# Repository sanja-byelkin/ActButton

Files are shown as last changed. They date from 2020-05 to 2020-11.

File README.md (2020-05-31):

# ActButton

It is a software for MQTT button.
On pressing button it:
* switches its power on
* connects to a Wifi
* connects to a MQTT server
* sends a message to a topic you setup (voltage * 1000)
* switches itself off

(above takes several seconds)

# Setup

If the button was not setup or can not connect to wifi or you continue to
press button for long time (about 12 sec) it will create Wifi network for
setup (then you can release button).

Default wifi for setup is "ActButton" and password is "ab1234567890ab" (it
can (and shoud!) be changed in setup). When you connect to the setup Wifi all web
connections will redirected to the button setup web page.
On the setup page there is http buttons:
* OK - save parameters and shutdown
* CANCEL - shutdown
* RESET - remove setup (format data partition of the esp8266 flash) and shutdown
* UPDATE - update software with given file and restart

# Hardware

* D1 Mini ESP8266 module
* LiFePo4 14500 (500mAh) battery
* ndp6020p MOSFET
* 1000 µF Electrolitic capasitor
* push button

# Circuit

Idea by Andreas Spiess ( https://www.youtube.com/channel/UCu7_D0o48KbfhpEohoP7YSQ )

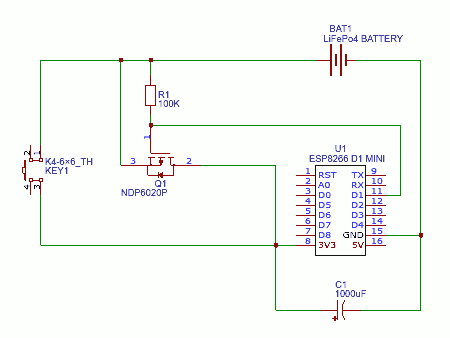
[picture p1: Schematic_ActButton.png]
ActButton Schematic


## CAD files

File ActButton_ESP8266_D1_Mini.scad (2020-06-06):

$fn=50;
WALL= 0.4*3;
S_WALL= 0.2;
TOLLERANCE= 0.03;

// no belt if 0
BELT_THICKNESS= 0.7;
BELT_W= 20;
BELT_ANGLE= 45;

VOLUME_2= "COMBO"; // "MIN", "MID", "MAX", "COMBO"


BATT_D= 14.5 + TOLLERANCE*2 + BELT_THICKNESS*2;
BATT_L= 50.5 + TOLLERANCE*2;
CAPACITOR_D= 14.5 + TOLLERANCE*2;
CAPACITOR_L= 22 + TOLLERANCE*2;
ESP_W= 26 + TOLLERANCE*2;
ESP_L= 35 + TOLLERANCE*2;
ESP_H= 10 + TOLLERANCE*2;
ESP_RH= 2;

CONT_D= 1.2;
CONT_M= 5 - CONT_D;
CONT_P= 3 - CONT_D;

BUTTON_PLATFORM= 10;
BUTTON_GAP= 4.2;
BUTTON_PRESS= 4;
BUTTON_OVERLAP= 0.4;
BUTTON_WALL_GAP=4;

LED_WINDOW= 12;



BOX_W= max(5*WALL + BATT_D + CAPACITOR_D,
           3*WALL + ESP_W);
BOX_L= max(4*WALL + BATT_L,
           2*WALL + CAPACITOR_L,
           2*WALL + ESP_L);
BOX_H= 4*WALL + max(BATT_D, CAPACITOR_D) + ESP_H;

BUTTON_WINDOW_L= (BUTTON_WALL_GAP*2 + BUTTON_PLATFORM -2*WALL);
BUTTON_WINDOW_W= BOX_W-6*WALL;

// cutting tool for cut_cube
module cuting_side(x,y,a)
{
    h= x*tan(a);
    rotate([90,0,0])
    linear_extrude(height=y, center=true)
    polygon(points = [[0,0],[x,0],[x,h]]);
}

// cube with well-printed "supports"
module cut_cube(dim, angle)
{
    down= max(dim[0], dim[1])/2*tan(angle);
    h= dim[2] + down;
    translate([0, 0 , +h/2 -(down + dim[2]/2)])
    difference()
    {
        cube([dim[0], dim[1], h], center=true);
        translate([0, 0 , -h/2])
        cuting_side(x= dim[0]/2, y= dim[1], a=angle);
        translate([0, 0 , -h/2])
        mirror([1,0,0])
        cuting_side(x= dim[0]/2, y= dim[1], a=angle);
        translate([0, 0 , -h/2])
        rotate([0,0,90])
        cuting_side(x= dim[1]/2, y= dim[0], a=angle);
        translate([0, 0 , -h/2])
        mirror([0,1,0])
        rotate([0,0,90])
        cuting_side(x= dim[1]/2, y= dim[0], a=angle);
    }
}

// long and overcomplicated way to make a barierr
module cubic_barrier(h,l,r,cut)
{
    hh= sqrt(h*h/2);
    difference()
    {
        translate([0,0,h/2])
        rotate([0,45,0])
        cube([hh,l,hh], center= true);
        if (cut)
        {
            translate([(r? -hh : 0),-(l+1)/2,-1])
            cube([hh,l+1,h+2]);
        }
    }
}

// something 1-like shaped
module limit_w_barrier(w,l,h1,h2,r)
{
    translate([-w/2,-l/2,0])
    cube([w,l,h1+h2]);
    translate([(r?w/2:-w/2),0,h1])
    cubic_barrier(h=h2,l=l,r=r, cut=false);
}

// Cage for 6x6mm button
module button_66cage(platform, gap)
{
    // 6x6mm button parameters
    BUTTON_SL= 3.5;
    BUTTON_S= 6;
    BUTTON_SH= 4;
    BUTTON_B= 0.5;
    translate([0, 0, gap/2])
    cut_cube([platform, BUTTON_SL, gap +0.01], angle=45);
    translate([0, 0, gap/2])
    cut_cube([BUTTON_SL, platform, gap +0.01], angle=45);
        
    // real botton cage
    barier= (platform-BUTTON_S)/2 - TOLLERANCE;
        
    translate([(platform/2 - barier/2), 0, gap - 0.01])
    limit_w_barrier(l= BUTTON_SL, w= barier, h1= BUTTON_SH + 0.01, h2=BUTTON_B,r=false);

    translate([-(platform/2 - barier/2), 0, gap - 0.01])
    limit_w_barrier(l= BUTTON_SL, w= barier, h1= BUTTON_SH + 0.01, h2= BUTTON_B, r= true);
        
    translate([0, (platform/2 - barier/2), gap - 0.01])
    rotate(90)
    limit_w_barrier(l= BUTTON_SL, w= barier,h1= BUTTON_SH + 0.01, h2= BUTTON_B, r= false);
        
    translate([0, -(platform/2 - barier/2), gap - 0.01])
    rotate(90)
    limit_w_barrier(l= BUTTON_SL, w= barier,h1= BUTTON_SH + 0.01, h2= BUTTON_B, r= true);
}

// D shaped cut to put cylinder in it
module cylinder_cut(d, l, h)
{
    cylinder(d=d, h=l, center= true);
    translate([0, -h/2, 0])
    cube([d, h, l], center= true);
}

// "swift-tail" :)
module s_tail(w1,w2,l,h)
{
    rotate([90,0,0])
    linear_extrude(height=l, center=true)
    polygon(points = [[-w1/2,-h/2],
                      [-w2/2,+h/2],
                      [+w2/2,+h/2],
                      [+w1/2,-h/2]]);
}

// slider-cover shape
module slider_cover(h, w, l, top)
{
    ww= w + 2*h;
    difference()
    {
        union()
        {
            translate([0, 0, h/2])
            if (top)
                s_tail(w1=w, w2=ww, l=l, h=h);
            else
                s_tail(w1=ww, w2=w, l=l, h=h);
            translate([0, +h - l/2, -h/2 +0.01])
            cube([ww, h*2, h], center=true);
            translate([0, -h + l/2, -h/2 +0.01])
            cube([ww, h*2, h], center=true);
            translate([0, 0, -h/2 +0.01])
            cube([w, l - h*4, h], center=true);
        }
        translate([-h/2 + ww/2, -h + l/2, 0])
        cube([h, h*2, 8*h], center=true);
        translate([+h/2 - ww/2, -h + l/2, 0])
        cube([h, h*2, 8*h], center=true);
    }
}

// Cut for battery contacts
module battery_cont(cd, centers_d, ch, cut)
{
    translate([+centers_d/2, 0, 0])
    cylinder(d= cd, h= ch, center=true);
    translate([-centers_d/2, 0, 0])
    cylinder(d= cd, h= ch, center=true);
    translate([0, 0, +cut/2 - ch/2])
    cube([centers_d, cd, cut], center=true);
}

// The box without cuts for its battery compartment
module button_top_cut_box()
{
    battery_comp= 3*WALL + BATT_D;
    difference()
    {
        // box
        cube([BOX_W, BOX_L, BOX_H], center= true);

        // Cut for electronics
        translate([0, 0, -(BOX_H - battery_comp)/2 + BOX_H/2 + 0.01])
        cube([BOX_W - 4*WALL, BOX_L - 2*WALL, BOX_H -  battery_comp], center= true);
        translate([+(CAPACITOR_D/2) - (BOX_W/2 - 2*WALL), 0, - (CAPACITOR_D/2 + BOX_H/2) + (VOLUME_2 == "MIN" ? (battery_comp + ESP_RH) : (CAPACITOR_D + WALL))])
        if (VOLUME_2 == "MIN" || VOLUME_2 == "MID")
        {
            rotate([-90, 0, 0])
            cylinder_cut(d= CAPACITOR_D, l= BOX_L - 2*WALL, h= BOX_H);
        }
        else
        {
            //if there is belt, lets mame its cut even
            cl= min(CAPACITOR_L, (BELT_THICKNESS > 0 ? (BOX_L - 2*WALL - BELT_W - 2*WALL)/2 : BOX_L));
            l= BOX_L - 2*WALL - (VOLUME_2 == "MAX" ? 0: cl);
            translate([ 0, (VOLUME_2 == "MAX" ? 0 : - -cl/2), BOX_H/2 - CAPACITOR_D/2])
            difference()
            {
                cube([CAPACITOR_D, l, BOX_H], center=true);
                translate([ CAPACITOR_D/4, 0, -BOX_H/2])
                rotate([90,0,0])
                linear_extrude(height= l, center=true)
                polygon(points = [[0,0],[CAPACITOR_D/4, 0],[CAPACITOR_D/4,CAPACITOR_D/4]]);
            }
            if (VOLUME_2 != "MAX")
            {
                translate([0, -l/2 +WALL/2, (battery_comp + ESP_RH)
                - (CAPACITOR_D + WALL)])
                rotate([-90, 0, 0])
                cylinder_cut(d= CAPACITOR_D, l= cl+ WALL, h= BOX_H);
            }
        }
        
    }
    translate([0, BOX_L/2- WALL - BUTTON_PLATFORM/2 -BUTTON_GAP, -BOX_H/2 + BATT_D + 3*WALL])
    button_66cage(platform= BUTTON_PLATFORM, gap=BUTTON_GAP);
}

// The box body
module button_box()
{
    difference()
    {
        button_top_cut_box();

        // Battery compartment
        translate([-(BATT_D/2) + (BOX_W/2 - 2*WALL), 0, (BATT_D/2) - (BOX_H/2 - 2*WALL)])
        rotate([90, 0, 0])
        cylinder_cut(d= BATT_D, l= BATT_L, h= BATT_D/2+ 2*WALL + 0.01);
        // Cut for battery cover
        translate([-(BATT_D + 2*WALL)/2 + BOX_W/2 - WALL, 0, +WALL - BOX_H/2])
        slider_cover(h= WALL+TOLLERANCE*2, w= BATT_D, l= BOX_L, top= false);
        // top cover
        translate([0, 0, -WALL + BOX_H/2])
        rotate([0, 180, 0])
        slider_cover(h= WALL+TOLLERANCE*2, w= BOX_W-4*WALL, l= BOX_L, top= true);
        // Cut battery contacts
        translate([ (BOX_W/2 - 2*WALL) - BATT_D/2, +(BATT_L + CONT_D)/2 - 0.01, 0])
        battery_cont(cd= CONT_D, centers_d= CONT_P, ch=BOX_H-8*WALL, cut= BATT_D - 4*WALL);
        translate([ (BOX_W/2 - 2*WALL) - BATT_D/2, -(BATT_L + CONT_D)/2 + 0.01, 0])
        battery_cont(cd= CONT_D, centers_d= CONT_M, ch=BOX_H-8*WALL, cut= BATT_D - 4*WALL);
        // Minus
        translate([-(BOX_W/2 - 2*WALL) + BATT_D/2, -BOX_L/4, -BOX_H/2 + S_WALL/2 -0.01])
        cube([WALL, 3*WALL, S_WALL], center=true);
        // Plus
        translate([-(BOX_W/2 - 2*WALL) + BATT_D/2, +BOX_L/4, -BOX_H/2 + S_WALL/2 -0.01])
        cube([3*WALL, WALL, S_WALL], center=true);
        translate([-(BOX_W/2 - 2*WALL) + BATT_D/2, +BOX_L/4, -BOX_H/2 + S_WALL/2 -0.01])
        cube([WALL, 3*WALL, S_WALL], center=true);

        if (BELT_THICKNESS > 0)
        {
            l= (2*WALL + CAPACITOR_D/2)/cos(BELT_ANGLE);
            translate([0, 0, -BOX_H/2 + 3*WALL + BELT_THICKNESS/2])
            rotate([0, BELT_ANGLE, 0])
            translate([-l/2 + 2*WALL, 0, 0])
            cube([l, BELT_W, BELT_THICKNESS], center=true);
        }
    }
}

// half-cylinder
module h_cylinder(d,h)
{
    difference()
    {
        cylinder(d=d, h=h, center=true);
        translate([0, d/2, 0])
        cube([d,d,2*h],center=true);
    }
}
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

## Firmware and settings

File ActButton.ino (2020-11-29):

#include "FS.h"
#include <ESP8266WiFi.h>
#include <WiFiClient.h>
#include <PubSubClient.h>
#include <ESP8266WebServer.h>
#include <DNSServer.h>

//#include "cfg_file.h"
void send_field_uint(const __FlashStringHelper *label,
                     const __FlashStringHelper *name,
                     void *vval, uint8_t mlen, bool hr);
void send_field_str(const __FlashStringHelper *label,
                    const __FlashStringHelper *name,
                    void *vval, uint8_t mlen, bool hr);
void send_field_8ui(const __FlashStringHelper *label,
                    const __FlashStringHelper *name,
                    void *vval, uint8_t mlen, bool hr);
void send_field_hex(const __FlashStringHelper *label,
                    const __FlashStringHelper *name,
                    void *vval, uint8_t mlen, bool hr);
bool read_bytes_wrapper(File &f, void *vval, uint8_t mlen);
bool read_str_wrapper(File &f, void *vval, uint8_t mlen);
bool read_uint16_wrapper(File &f, void *vval, uint8_t mlen);
bool write_bytes_wrapper(File &f, void *vval, uint8_t mlen);
bool write_str_wrapper(File &f, void *vval, uint8_t mlen);
bool write_uint16_wrapper(File &f, void *vval, uint8_t mlen);
bool get_field_str(void *vval, const String &str, uint8_t mlen);
bool get_field_ui16(void *vval, const String &str, uint8_t mlen);

// Use Analog-to-Digital converter for input voltage
ADC_MODE(ADC_VCC);

// a bit of debug facilities
//#define DEBUG_ON
#ifdef DEBUG_ON
#define DEBUG_BEGIN do {Serial.begin(115200);Serial.setDebugOutput(true);} while(0);
//#define DEBUG_BEGIN Serial.begin(921600);
#define DEBUG_PRINTLN(x) Serial.println(x)
#define DEBUG_PRINT(x) Serial.print(x)
#else
#define DEBUG_BEGIN
#define DEBUG_PRINTLN(x)
#define DEBUG_PRINT(x)
#endif //DEBUG_ON

/**********************************************************************
  Setup variables and constants
**********************************************************************/

const uint16_t WiFiSetupChannel= 1;
const uint16_t DnsPort= 53;

//Control of MOFSET
const int PwrCtrlPin= D1;

const char emptyStr[]="";
char* ssid     = (char*)emptyStr;
char* password = (char*)emptyStr;
char* mqtt_serv= (char*)emptyStr;
int   mqtt_port= 1883;
char* mqtt_devc= (char*)emptyStr;
char* mqtt_topc= (char*)emptyStr;
char* mqtt_user= (char*)emptyStr;
char* mqtt_pswd= (char*)emptyStr;
char* setup_ssid= (char*)emptyStr;
char* setup_pssw= (char*)emptyStr;
uint8_t wifi_channel= 0;
uint8_t wifi_ap_mac[6]= {0,0,0,0,0,0}; // mark it unset

bool is_wifi_data_set()
{
  for(uint8_t i= 0; i < 6; i++)
    if (wifi_ap_mac[i])
      return true;
  return false;
}

struct VarDesc
{
  const char *label;
  const char *name;
  void *var;
  void (*out_processor)(const __FlashStringHelper *label, const __FlashStringHelper *name, void* param, uint8_t mlen, bool hr);
  bool (*read_cfg)(File &f, void *vval, uint8_t mlen);
  bool (*write_cfg)(File &f, void *vval, uint8_t mlen);
  bool (*in_processor)(void *vval, const String &str, uint8_t mlen);
  uint8_t group;
  uint8_t max_len;
};

const char br_tag[]         PROGMEM= "<br>";
const char ssid_l[]         PROGMEM= "WiFi";
const char ssid_n[]         PROGMEM= "ssid";
const char password_l[]     PROGMEM= "WiFi Password";
const char password_n[]     PROGMEM= "password";
const char mqtt_serv_l[]    PROGMEM= "MQTT Server Address";
const char mqtt_serv_n[]    PROGMEM= "mqtt_serv";
const char mqtt_port_l[]    PROGMEM= "MQTT port";
const char mqtt_port_n[]    PROGMEM= "mqtt_port";
const char mqtt_devc_l[]    PROGMEM= "This devce name";
const char mqtt_devc_n[]    PROGMEM= "mqtt_devc";
const char mqtt_topc_l[]    PROGMEM= "MQTT topic";
const char mqtt_topc_n[]    PROGMEM= "mqtt_topc";
const char mqtt_user_l[]    PROGMEM= "MQTT user";
const char mqtt_user_n[]    PROGMEM= "mqtt_user";
const char mqtt_pswd_l[]    PROGMEM= "MQTT password";
const char mqtt_pswd_n[]    PROGMEM= "mqtt_pswd";
const char setup_ssid_l[]   PROGMEM= "Setup SSID";
const char setup_ssid_n[]   PROGMEM= "setup_ssid";
const char setup_pssw_l[]   PROGMEM= "Setup password";
const char setup_pssw_n[]   PROGMEM= "setup_pssw";
const char wifi_channel_l[] PROGMEM= "Wifi channel";
const char wifi_ap_mac_l[]  PROGMEM= "Wifi AP MAC";

const VarDesc Parameters[]=
{
  {wifi_channel_l, 0,            &wifi_channel, &send_field_8ui,
  &read_bytes_wrapper,  &write_bytes_wrapper,  0,
  0,  1},

  {wifi_ap_mac_l,  0,            wifi_ap_mac, &send_field_hex,
  &read_bytes_wrapper,  &write_bytes_wrapper,  0,
  0,  6},

  {ssid_l,         ssid_n,       &ssid,        &send_field_str,
  &read_str_wrapper,    &write_str_wrapper,    &get_field_str,
  1, 30},

  {password_l,     password_n,   &password,    &send_field_str,
  &read_str_wrapper,    &write_str_wrapper,    &get_field_str,
  1, 40},

  {mqtt_serv_l,    mqtt_serv_n,  &mqtt_serv,   &send_field_str,
  &read_str_wrapper,    &write_str_wrapper,    &get_field_str,
  2, 50},

  {mqtt_port_l,    mqtt_port_n,  &mqtt_port,   &send_field_uint,
  &read_uint16_wrapper, &write_uint16_wrapper, &get_field_ui16,
  2, 10},

  {mqtt_devc_l,    mqtt_devc_n,  &mqtt_devc,   &send_field_str,
  &read_str_wrapper,    &write_str_wrapper,    &get_field_str,
  2, 10},

  {mqtt_topc_l,    mqtt_topc_n,  &mqtt_topc,   &send_field_str,
  &read_str_wrapper,    &write_str_wrapper,    &get_field_str,
  2, 50},

  {mqtt_user_l,    mqtt_user_n,  &mqtt_user,   &send_field_str,
  &read_str_wrapper,    &write_str_wrapper,    &get_field_str,
  2, 50},

  {mqtt_pswd_l,    mqtt_pswd_n,  &mqtt_pswd,   &send_field_str,
  &read_str_wrapper,    &write_str_wrapper,    &get_field_str,
  2, 50},

  {setup_ssid_l,   setup_ssid_n, &setup_ssid,  &send_field_str,
  &read_str_wrapper,    &write_str_wrapper,    &get_field_str,
  3, 20},

  {setup_pssw_l,   setup_pssw_n, &setup_pssw,  &send_field_str,
  &read_str_wrapper,    &write_str_wrapper,    &get_field_str,
  3, 50}
};

const char setup_file[] PROGMEM= "/ActButton.cfg";

/**********************************************************************
  Global objects (an old Arduino tradition :) )
**********************************************************************/

WiFiClient espClient;
PubSubClient mqtt(espClient);
int lvl= HIGH;
int counter;


ESP8266WebServer setup_server(80);
DNSServer *DnsServer;
void WifiSetMode(WiFiMode_t wifi_mode);
void WifiManagerBegin();

/**********************************************************************
  Arduino setup
**********************************************************************/

void setup()
{
  int bat;
  bool lwf_ok= false;
  unsigned long strt= millis();

  /* First suport power for this module */
  pinMode(PwrCtrlPin, OUTPUT);
  digitalWrite(PwrCtrlPin, LOW);

  DEBUG_BEGIN;
  DEBUG_PRINTLN("Start");

  /* Blinking to sho that we are alive */
  pinMode(LED_BUILTIN, OUTPUT);
  digitalWrite(LED_BUILTIN, (lvl=!lvl));

  /* Read Config */
  if(!SPIFFS.begin())
  {
    DEBUG_PRINTLN("Format SPIFFS");
    SPIFFS.format();
    SPIFFS.begin();
  }
  lwf_ok= readCfg();
  DEBUG_PRINT("Is read Config ok:");
  DEBUG_PRINTLN(lwf_ok);
  if (!lwf_ok)
    goto setup;

  /* Connect to Wifi */
  WifiSetMode(WIFI_STA);
  if (is_wifi_data_set())
    WiFi.begin(ssid, password, wifi_channel, wifi_ap_mac, true );
  else
    WiFi.begin(ssid, password);
  digitalWrite(LED_BUILTIN, (lvl=!lvl));


  /* Read battery vltage */
  bat= ESP.getVcc();
  DEBUG_PRINT("Batterie:");
  DEBUG_PRINTLN(ESP.getVcc());

  /* Wait for WiFi to be connected */
  counter= 1000;
  while (WiFi.status() != WL_CONNECTED)
  {
    if ((counter % 10) == 0)
    {
      digitalWrite(LED_BUILTIN, (lvl=!lvl));
      DEBUG_PRINT(".");
    }
    delay(10);
    if ((--counter)==0)
      goto setup;
  }
  DEBUG_PRINTLN(" connected!");

  /* if AP/channel we are conected to changed write config */
  if(wifi_channel != WiFi.channel() ||
     memcmp(wifi_ap_mac, WiFi.BSSID(), 6) != 0)
  {
    /* TODO: write only channel and AP MAC (if it has sens) */
    wifi_channel= WiFi.channel();
    memcpy(wifi_ap_mac, WiFi.BSSID(), 6);
    writeCfg();
  }
  digitalWrite(LED_BUILTIN, (lvl=!lvl));

  /* Connect to MQTT and sent the meaaege */
  mqtt.setServer(mqtt_serv, (int)mqtt_port);
  if (mqtt.connect(mqtt_devc, mqtt_user, mqtt_pswd))
  {
    char buff[20];
    digitalWrite(LED_BUILTIN, (lvl=!lvl));
    //itoa(millis() - strt, buff, 10);
    itoa(bat, buff, 10);
    mqtt.publish(mqtt_topc,buff);
    digitalWrite(LED_BUILTIN, (lvl=!lvl));
  }
  digitalWrite(LED_BUILTIN, (lvl=!lvl));
  /* disconnect from MQLL (to be sure that the message is sent) */
  mqtt.disconnect();
  DEBUG_PRINTLN("Mqtt Disconnect...");
  digitalWrite(LED_BUILTIN, (lvl=!lvl));

  /************
    Power down
  *************/
  digitalWrite(PwrCtrlPin, HIGH);

  /*
    If user keep pressing button wait 10 Sec to be sure about his/her
    intentions to enter setup
  */
  for(counter= 0; counter < 10; counter++)
  {
    digitalWrite(LED_BUILTIN, (lvl=!lvl));
    delay(1000);
  }

setup:
  /* Switch power support again to allow user use both hands during setup */
  digitalWrite(PwrCtrlPin, LOW);
  DEBUG_PRINTLN("SETUP!");

  /* setup wifi AP */
  WifiManagerBegin();
  DEBUG_PRINT("AP IP address: ");
  DEBUG_PRINTLN(WiFi.softAPIP());
  digitalWrite(LED_BUILTIN, (lvl=!lvl));

  /* setup Web server */
  setup_server.on("/", handleRoot);
  setup_server.onNotFound(handleNotFound);
  setup_server.on("/sv", handleSave);
  setup_server.on("/cn", handleShutdown);
  setup_server.on("/rs", handleReset);
  setup_server.on("/up", HTTP_POST, handleUpdate, handleUpdateProgress);
  setup_server.begin();
  counter= 0;
  delay(100);
  digitalWrite(LED_BUILTIN, (lvl=!lvl));
}

/**********************************************************************
  Arduino loop
**********************************************************************/

void loop()
{
  // fast blinking to show we are in wetup mode
  if (counter % 40 == 0)
    digitalWrite(LED_BUILTIN, (lvl=!lvl));

  // process requests
  setup_server.handleClient();
  if (DnsServer)
    DnsServer->processNextRequest();
  delay(10);
  counter++;
}

/**********************************************************************
  WEB interface
**********************************************************************/

static char* itoa(char *buff, uint8_t len, unsigned int val)
{
  char *c= buff + (len - 1);
  *(c)= '\0';
  if (val)
  {
    while (val && c > buff)
    {
      *(--c)= '0' + (val%10);
      val/= 10;
    }
  }
  else
    *(--c)= '0';
  return c;
}

// show field unsigned integer field on web
void send_field_uint(const __FlashStringHelper *label,
                     const __FlashStringHelper *name,
                     void *vval, uint8_t mlen, bool hr)
{
  unsigned int val= *((unsigned int*)vval);
  char buff[20];
  char *c= itoa(buff, sizeof(buff), val);
  send_field_str(label, name, (void*)&c, mlen, hr);
}

// show field string field on web
void send_field_str(const __FlashStringHelper *label,
                    const __FlashStringHelper *name,
                    void *vval, uint8_t mlen, bool hr)
{
  char *val= *((char **)vval);
  String content;
  char *c= val;
  content.reserve(128);
  content= (hr ? "<hr>": "");
  content+= F("<label for=\"");
  content+= name;
  content+= F("\">");
  content+= label;
  content+= F("</label><br><input type=\"text\" id=\"");
  content+= name;
  content+= F("\" name=\"");
  content+= name;
  content+= F("\" value=\"");
  for(char *c= val; (*c); c++)
  {
    if ((*c) == '"')
      content+="&#x22;";
    else
      content+= (*c);
  }
  content+= F("\"><br>");
  setup_server.sendContent(content);
}


// show byte read only on web
void send_field_8ui(const __FlashStringHelper *label,
                    const __FlashStringHelper *name,
                    void *vval, uint8_t mlen, bool hr)
{
  char buff[4];
  uint8_t val= *((uint8_t*)vval);
  char *c= itoa(buff, sizeof(buff), val);
  String content;
  content.reserve(128);
  content= (hr ? "<hr>": "");
  content+= label;
  content+= FPSTR(br_tag);
  content+= c;
  content+= FPSTR(br_tag);
  setup_server.sendContent(content);
}

// show byte string in hex on web (read only)
void send_field_hex(const __FlashStringHelper *label,
                    const __FlashStringHelper *name,
                    void *vval, uint8_t mlen, bool hr)
{
  uint8_t *val= ((uint8_t*)vval);
  String content;
  char s[]="0123456789ABCDEF";
  content.reserve(128);
  content= (hr ? "<hr>": "");
  content+= label;
  content+= FPSTR(br_tag);

  for(int i= 0; i < mlen; i++)
  {
    content+= s[(val[i] >> 4)];
    content+= s[(val[i] & 0x0F)];
    content+= ' ';
  }
  content+= FPSTR(br_tag);
  setup_server.sendContent(content);
}

// root web page with setup
void handleRoot()
{
  DEBUG_PRINTLN("Root page of web");
  if (!setup_server.chunkedResponseModeStart(200, "text/html"))
  {
    setup_server.send(505, F("text/html"), F("HTTP1.1 required"));
    return;
  }
  setup_server.sendContent(F("<!DOCTYPE html><html><body><h3>Action button Setup</h3><form action=\"/sv\" method=\"POST\">"));

  uint8_t prev_group= 0;
  for (int i= 0; i < sizeof(Parameters)/sizeof(VarDesc); i++)
  {
    //DEBUG_PRINT("show ");
    //DEBUG_PRINTLN(FPSTR(Parameters[i].label));
    (*Parameters[i].out_processor)(FPSTR(Parameters[i].label),
    FPSTR(Parameters[i].name), Parameters[i].var, Parameters[i].max_len, prev_group!=Parameters[i].group);
    prev_group= Parameters[i].group;
  }
  setup_server.sendContent(F("<hr><input type=\"submit\" value=\"OK\"></form><hr>"
                             "<form action=\"/cn\"><input type=\"submit\" value=\"CANCEL\"></form><hr>"
                             "<form action=\"/rs\"><input type=\"submit\" value=\"RESET\"></form><hr>"
                             "<h3>Firmware update:</h3>"
                             "<form action=\"/up\" method=\"POST\" enctype=\"multipart/form-data\">"
                               "<input type=\"file\" name=\"update\"><br>"
                               "<input type=\"submit\" value=\"UPDATE\"></form><hr>"
                             "</body></html>"));
  setup_server.chunkedResponseFinalize();
}

/*
  Reads string send to web server.

  Retund FALSE on success and TRUE on fail
*/
bool get_field_str(void *vval, const String &str, uint8_t mlen)
{
  if (str.length() > mlen)
    return true;

  uint8_t alen= str.length() + 1;
  char *res= (char*)malloc(alen);
  if (!res)
    return true;

  strlcpy(res, str.c_str(), alen);
  if (*((char **)vval) != emptyStr)
    free(*((char **)vval));
  *((char **)vval)= res;
  return false; //success
}

/*
  Reads uint16_t send to web server.

  Retund FALSE on success and TRUE on fail
*/
bool get_field_ui16(void *vval, const String &str, uint8_t mlen)
{
  if (str.length() > mlen)
    return true;

  *((uint16_t *)vval)= str.toInt();
  return false; //success
}

// take and save parameters from web
void handleSave()
{
  // check all parameters
  bool ok= true;
  for (int i= 0; i < sizeof(Parameters)/sizeof(VarDesc); i++)
  {
    if (!FPSTR(Parameters[i].name))
      continue;
    if (setup_server.hasArg(FPSTR(Parameters[i].name)))
    {
      if ((*Parameters[i].in_processor)(Parameters[i].var,
                                        setup_server.arg(FPSTR(
                                                         Parameters[i].name)),
                                        Parameters[i].max_len))
        ok= false;
    }
    else
      ok= false;
  }
  if (ok)
  {
    // Parameters are OK, save and power off
    // but first reset cached data
    wifi_channel= 0;
    wifi_ap_mac[0]= wifi_ap_mac[1]= wifi_ap_mac[2]= wifi_ap_mac[3]= wifi_ap_mac[4]= wifi_ap_mac[5]= 0;
    writeCfg();
    setup_server.send(200, "text/html",
                      F("<!DOCTYPE html><html><body><h3>"
                        "Config written. Shutdown..."
                        "</h3></body></html>"));
    delay(500);
    digitalWrite(PwrCtrlPin, HIGH);
    return;
  }
  // show setup page
  handleRoot();
}

// CANCEL button - just power off
void handleShutdown()
{
  setup_server.send(200, "text/html",
                    F("<!DOCTYPE html><html><body><h3>"
                      "Shutdown..."
                      "</h3></body></html>"));
  delay(500);
  digitalWrite(PwrCtrlPin, HIGH);
}

// RESET button, format FS and power off
void handleReset()
{
  DEBUG_PRINT("Firmaring memory... ");
  SPIFFS.format();
  DEBUG_PRINTLN("Done.");
  setup_server.send(200, "text/html",
                    F("<!DOCTYPE html><html><body><h3>"
                      "Setings removed.Shutdown..."
                      "</h3></body></html>"));
  delay(500);
  digitalWrite(PwrCtrlPin, HIGH);
}

// if page is not found - redirect on root page
void handleNotFound(void)
{
 setup_server.sendHeader("Location", "/",true);//Redirect to our html web page
 setup_server.send(302, "text/plane","");
}


// Over Air Update taken from WebUpdate example
void handleUpdate(void)
{
  setup_server.sendHeader("Connection", "close");
  setup_server.send(200, "text/plain", (Update.hasError()) ? "FAIL" : "OK");
  ESP.restart();
}

// Over Air Update taken from WebUpdate example
void handleUpdateProgress(void)
{
  HTTPUpload& upload = setup_server.upload();
  if (upload.status == UPLOAD_FILE_START)
  {
    WiFiUDP::stopAll();
    DEBUG_PRINT("Update: ");
    DEBUG_PRINTLN(upload.filename.c_str());
    uint32_t maxSketchSpace = (ESP.getFreeSketchSpace() - 0x1000) & 0xFFFFF000;
    //start with max available size
    if (!Update.begin(maxSketchSpace))
    {
#ifdef DEBUG_ON
      Update.printError(Serial);
#endif //DEBUG_ON
    }
  }
  else if (upload.status == UPLOAD_FILE_WRITE)
  {
    if (Update.write(upload.buf, upload.currentSize) != upload.currentSize)
    {
#ifdef DEBUG_ON
      Update.printError(Serial);
#endif //DEBUG_ON
    }
  }
  else if (upload.status == UPLOAD_FILE_END)
  {
    //true to set the size to the current progress
    if (Update.end(true))
    {
      DEBUG_PRINT("Update Success: ");
      DEBUG_PRINTLN(upload.totalSize);
      DEBUG_PRINTLN("Rebooting...");
    }
    else
    {
#ifdef DEBUG_ON
      Update.printError(Serial);
#endif //DEBUG_ON
    }
  }
  yield();
}

/**********************************************************************
  WIFi management
**********************************************************************/

/*
  Switches WiFi modes

  Inspired by Tasmota project
*/
void WifiSetMode(WiFiMode_t wifi_mode)
{
  if (WiFi.getMode() == wifi_mode)
    return;

  if (wifi_mode != WIFI_OFF)
  {
    WiFi.forceSleepWake(); // Make sure WiFi is really active.
    delay(100);
  }

  uint32_t retry = 2;
  while (!WiFi.mode(wifi_mode) && retry--)
  {
    DEBUG_PRINTLN("Retry set Mode...");
    delay(100);
  }
  digitalWrite(LED_BUILTIN, (lvl=!lvl));

  if (wifi_mode == WIFI_OFF)
  {
    delay(1000);
    WiFi.forceSleepBegin();
    digitalWrite(LED_BUILTIN, (lvl=!lvl));
    delay(1);
  }
  else
  {
    delay(30); // Must allow for some time to init.
  }
}

/*
  Switch on setup AP

  Inspired by Tasmota project
*/
void WifiManagerBegin()
{
  WifiSetMode(WIFI_AP);

  DnsServer = new DNSServer();

  // bool softAP(const char* ssid, const char* passphrase = NULL, int channel = 1, int ssid_hidden = 0, int max_connection = 4);
  if (setup_ssid == emptyStr)
    WiFi.softAP("ActiveButton", "ab1234567890ab", WiFiSetupChannel, 0, 1);
  else
    WiFi.softAP(setup_ssid, setup_pssw, WiFiSetupChannel, 0, 1);

  delay(500); // Without delay I've seen the IP address blank
  digitalWrite(LED_BUILTIN, (lvl=!lvl));

  /* Setup the DNS server redirecting all the domains to the apIP */
  DnsServer->setErrorReplyCode(DNSReplyCode::NoError);
  DnsServer->start(DnsPort, "*", WiFi.softAPIP());
}

/**********************************************************************
  Configuration interface
**********************************************************************/

bool read_bytes_wrapper(File &f, void *vval, uint8_t mlen)
{
  return read_cfg_bytes(f, ((uint8_t *)vval), mlen);
}
bool read_str_wrapper(File &f, void *vval, uint8_t mlen)
{
  return (*((char **)vval)= read_cfg_string(f, mlen)) != NULL;
}
bool read_uint16_wrapper(File &f, void *vval, uint8_t mlen)
{
  return read_cfg_uint16(f, *((uint16_t *)vval));
}

/*
  Reads all confuguration

  return TRUE on success and FALSE on fail
*/
bool readCfg()
{
  DEBUG_PRINTLN("read_cfg");
  if (!SPIFFS.exists(FPSTR(setup_file)))
  {
    DEBUG_PRINTLN("No cfg found");
    return false;
  }

  File f = SPIFFS.open(FPSTR(setup_file), "r");
  if (!f)
  {
    DEBUG_PRINTLN("Can't cfg open");
    return false;
  }

  // check file version
  if (check_leader(f, "AB") != 1)
  {
    DEBUG_PRINTLN("Bad cfg header");
    goto err;
  }

  // Free setup strings
  for (int i= 0; i < sizeof(Parameters)/sizeof(VarDesc); i++)
  {
    if(Parameters[i].out_processor == &send_field_str)
    {
      char *v= *((char **)Parameters[i].var);
      if (v != emptyStr)
        free(v);
      *((char **)Parameters[i].var)= 0;
    }
  }
  // Read setup
  for (int i= 0; i < sizeof(Parameters)/sizeof(VarDesc); i++)
  {
    DEBUG_PRINT("Read cfg :");
    DEBUG_PRINTLN(FPSTR(Parameters[i].label));
    if(!(*Parameters[i].read_cfg)(f, Parameters[i].var, Parameters[i].max_len))
      goto err;
  }

  f.close();
  return true;

err:
  // Reading setup failed so we clean up variables
  DEBUG_PRINTLN("cfg read Error!!!");
  for (int i= 0; i < sizeof(Parameters)/sizeof(VarDesc); i++)
  {
    if(Parameters[i].out_processor == &send_field_str)
    {
      if (*((char **)Parameters[i].var) != emptyStr)
        free(*((char **)Parameters[i].var));
      *((char **)Parameters[i].var)= (char*)emptyStr;
    }
  }
  DEBUG_PRINTLN("Parameters freed");
  f.close();
  return false;
}


bool write_bytes_wrapper(File &f, void *vval, uint8_t mlen)
{
  return write_cfg_bytes(f, ((uint8_t *)vval), mlen);
}
bool write_str_wrapper(File &f, void *vval, uint8_t mlen)
{
  return write_cfg_string(f, *((char **)vval));
}
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

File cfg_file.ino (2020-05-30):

#include "cfg_file.h"
#include <FS.h>

/*
  Check file header and file version

  f                      file to read
  example                reference to string with 2 bytes of the file
                         signature
  returns 0 on error, otherwise - version
*/
uint8_t check_leader(File &f, char *example)
{
  DEBUG_PRINT("Check leader record"); DEBUG_PRINTLN(example);
  char lead_record[3];
  if (f.readBytes(lead_record, 3) != 3)
    return 0;
  if (lead_record[0] != example[0] ||
      lead_record[1] != example[1])
    return 0;
  return lead_record[2];
}

/*
  Reads string from configuration file

  f                      file to read
  max_len                maximum possible length of the string

  returns allocated string or 0 in case of error
*/
char *read_cfg_string(File &f, uint8_t max_len)
{
  char *str;
  uint8_t len;
  if (f.readBytes((char*)&len, 1) != 1 || len > max_len)
    return NULL;
  if ((str= (char*)malloc(len+1)) == NULL)
    return NULL;
  if (f.readBytes(str, len) != len)
  {
    free(str); str= NULL;
    return NULL;
  }
  str[len]= '\0';
  return str;
}

bool write_cfg_string(File &f, const char *str)
{
  DEBUG_PRINTLN("write_cfg_string");
  uint8_t len= strlen(str);
  DEBUG_PRINTLN(len);
  if (f.write((const byte*)&len, 1)!= 1)
    return false;
  DEBUG_PRINTLN("len written");
  if (f.write((const byte*)str, len)!= len)
    return false;
  DEBUG_PRINTLN("write OK");
  return true;
}

bool read_cfg_uint16(File &f, uint16_t &res)
{
  // we do not care about arhitecture byte order
  if ((f.readBytes((char*)&res, 2) == 2))
    return true;
  res= 0;
  return false;
}

bool write_cfg_uint16(File &f, uint16_t res)
{
  // we do not care about arhitecture byte order
  return (f.write((const byte*)&res, 2) == 2);
}

bool read_cfg_int16(File &f, int16_t &res)
{
  // we do not care about arhitecture byte order
  if ((f.readBytes((char*)&res, 2) == 2))
    return true;
  res= 0;
  return false;
}

bool write_cfg_int16(File &f, int16_t res)
{
  // we do not care about arhitecture byte order
  return (f.write((const byte*)&res, 2) == 2);
}

bool read_cfg_bytes(File &f, uint8_t *res, uint8_t len)
{
  if ((f.readBytes((char*)res, len) == len))
    return true;
  res= 0;
  return false;
}

bool write_cfg_bytes(File &f, uint8_t *res, uint8_t len)
{
  return (f.write((const byte*)res, len) == len);
}

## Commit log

2020-05-31 Sources made tide and commented. Removed traces of try and fail aproaches :)
    [ActButton.ino]
2020-05-31 Schematic added.
2020-06-02 Box .scad file added
    [ActButton_ESP8266_D1_Mini.scad]
2020-06-05 Belt (or strip) for easy battery taking out added.
    4 type of electronics compartment added.
    [ActButton_ESP8266_D1_Mini.scad]
2020-06-06 better visible click place
    [ActButton_ESP8266_D1_Mini.scad]
2020-11-29 Fixed problem with reconfiguring for a new access point
    [ActButton.ino]
